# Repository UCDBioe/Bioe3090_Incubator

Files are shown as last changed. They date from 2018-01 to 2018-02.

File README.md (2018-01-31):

Required Libraries
-------------------
* PID_v1
* DallasTemperature
* OneWire

TODO
-----
* students update P,I,D vals in file
* cutoff for 45C heater
* cutoff for low voltage 

Bioe3090_Incubator
------------------

* **class TimeCheck(\_timeTrigger)** - Simple time trigger, needs to be polled to work. When polled with check\_trigger the model will return true if enough time has elapsed to satisfy the condition `(current_time - initial_time) > time_trigger`. If this condition has been met, the poll resets initial_time to current time and returns the boolean true, else false is returned.

* **void check_serial()** - Function that checks the serial port to see if data is available. If data is available, the function reads the data until a newline character is reached. The data is validated to be a correctly formatted JSON string. The JSON string is decoded and the decoded string is stored into global variables for the PID values and heater setpoint.

* **void assign_sensors()** - Startup function to assign the DS18B20 temperature sensors to the outside and inside positions within the incubator.

* **double convert_battery\_voltage(int analog\_reading)** - Converts an analogreading into the voltage of the battery. Uses the global values for the resistors in the voltage divider (resistV1, resistV2)

* **double print_temperature(DeviceAddress deviceAddress, bool jsonFlag)** - Function to print the temperature of a DS18B20 temperature device and to update temperature input for PID control. The temperature of the given device is printed to serial. This is useful for debugging. The temperature value is returned as a double. This can be used to update the temperature input for PID control in the main loop.

* **void json\_output(&double)** - Gathers data, builds JSON message and outputs message to the serial port of theArduino. JSON output string is encoded to contain information for the inside and outside tempertures, the PID output value and the time of the request. This data is then output on the serial port. Takes an address to a double as an input. This double is the input heater value for the PID control. Therefore, the PID heater input value is updated within the json\_output function.

* **void print_address(DeviceAddress deviceAddress)** - Prints the address of the given DS18B20 device.

* **void startup()** - Standard Arduino startup function. Starts serial coms, assigns sensors, set PID mode and sets heater setpoint.

* **void loop()** - Main Arduino program loop.

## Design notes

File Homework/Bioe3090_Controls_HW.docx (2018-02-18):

BIOE3090

Controls and Circuits Homework

30 Pts

Due: 2/13/2018 (Before Class, see canvas)

# Part I: C++ Primer (20 points)

The software provided on the UCDBioe Github account (see below for downloading instructions) contains all of the Arduino firmware required to control the field incubator and provides data communications between the Arduino and an optional terminal running Matlab. However, the firmware is missing failsafe modes for overheating the box and for over discharging the battery. Since it would be difficult to run the native Arduino firmware without the associated hardware, you have been provided an incomplete C++ program that you can use to develop some of the functions that would be useful in implementing these failsafes.

Overview of the bioe3090_HW.cpp code

The code consists of several function definitions and a main function. The main function defines variables and arrays used to make a randomly generated test dataset for battery voltages and temperature readings (battVals and tempVals). The batVals and tempVals array lengths can be changed and the arrays can be modified to have a low and high ranges that allow for the user to build a dataset that has a transition that would cause a failure alarm to be tripped. For example, the program sets up the battery arrays where the first 22 elements have an average value of 12.0V ±0.02V, and the rest of the elements have a value of 11.3V ±0.02V. The alarm should be tripped when the average battery voltage drops below 11.6V. See source code for further details.

The program also sets up two circular buffers to help filter some of the noise out of the data (tempBuffer, battBuffer). These circular buffers are a straightforward way to reduce some of the noise in real-world signals (emulated here as random noise). This is how they work:

For an incoming data stream

datastream = [12.1, 12.2, 12.3, 12.4, 12.7, 12.6, 12.5]

The buffer rolls along the data stream and holds a subset of the overall data

buffer = [12.2, 12.3, 12.4, 12.7]

average(buffer) = 12.4

When new data comes in, we shift the array values to the left and replace the last element with the new data.

buffer = [12.3, 12.4, 12.7, 12.6]

average(buffer) = 12.5

Gaussian distributed random noise is thus reduced by using an averaging filter.

Fixing the Code

The code provided should run, it just will not do what it is supposed to until you fix it. This should allow you to debug the software in a functional state. I would suggest compiling and test running the code early and often rather than trying to complete all of the sections then trying to debug the code. Also, the C-code required to complete this assignment should not be anything terribly advanced. Simple loops, print statements and arithmetic should be sufficient.

1. (5-pts)

Complete the code needed to print the values contained in the arrays in a nicely formatted way. Your output should look similar to Figure 1, where the values are aligned roughly in columns. The code sections are outlined in the bioe3090_HW.cpp file using the tags:

(STUDENT COMPLETE THIS SECTION >> -- HWS1----)

Your code goes here!!!!!!!!!!!!!! Place your code inside the bioe3090_HW.cpp file, but keep it between these tags so I can find it!

(STUDENT COMPLETE THIS SECTION << -- HWS1----)

2. (5-pts.) Complete the code needed to print the average values of a given array. The code sections are outlined in the bioe3090_HW.cpp file using the tags:

(STUDENT COMPLETE THIS SECTION >> -- HWS2----)

Your code goes here!!!!!!!!!!!!!! Place your code inside the bioe3090_HW.cpp file, but keep it between these tags so I can find it!

(STUDENT COMPLETE THIS SECTION << -- HWS2----)

3. (5-pts)

Complete the code needed to shift the buffer array and replace the last value with new data. This is the circular buffer used to average out noise in the signals. The code sections are outlined in the bioe3090_HW.cpp file using the tags:

(STUDENT COMPLETE THIS SECTION >> -- HWS3----)

Your code goes here!!!!!!!!!!!!!! Place your code inside the bioe3090_HW.cpp file, but keep it between these tags so I can find it!

(STUDENT COMPLETE THIS SECTION << -- HWS3----)

4. (5-pts)

Complete the code needed to check if a shutdown condition has been met. The code sections are outlined in the bioe3090_HW.cpp file using the tags:

(STUDENT COMPLETE THIS SECTION >> -- HWS4----)

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

(STUDENT COMPLETE THIS SECTION << -- HWS4----)

You may get a warning when you compile the code before you have fixed all of the sections: warning: control reaches end of non-void function [-Wreturn-type]. This warning simply means that you have a function defined to return some value and no value was returned. It will fix itself when you have valid return statements.

What to turn in for part 1

Your output should look similar to Figure 1. Turn in your .cpp file, put your name in the filename, i.e. steve_lammers_bioe3090_HW.cpp

Your code should compile and run. You will be mostly graded based on whether your code produces the correct output when it is compiled and run. You should not need to include any other libraries to do this assignment.

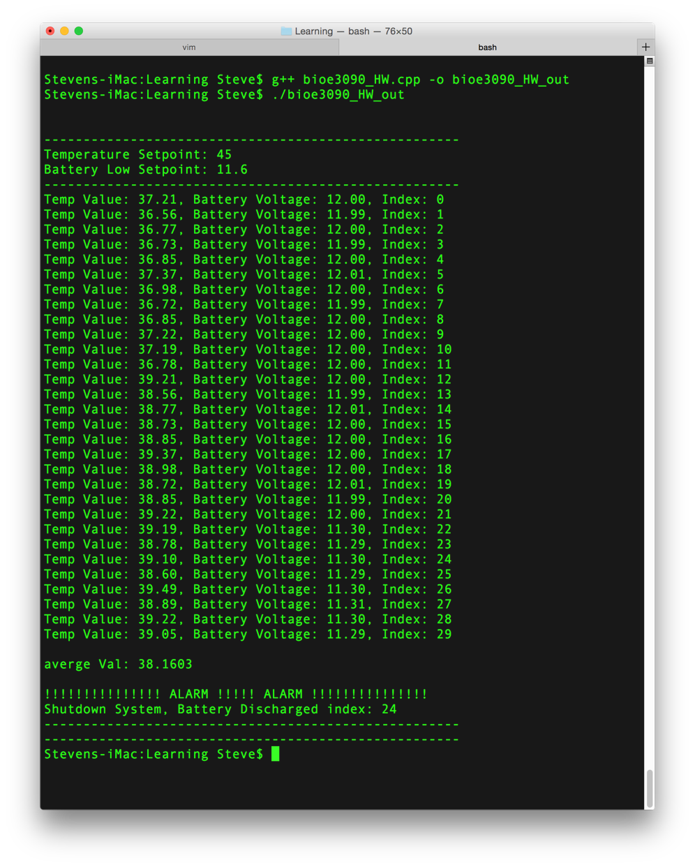
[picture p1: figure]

Figure 1: Output from completed C++ program.

Downloading Instructions:

The github repository is now public, so you can download the files needed to do this homework and to build your first design project.

https://github.com/UCDBioe/Bioe3090_Incubator

Remember to click the green "Clone or Download" button to be able to download the files. The homework is in the homework directory.

# Part 2: Soldering and Components (10 points)

Watch the “Soldering Video” and the “Multimeter Tutorial Video” posted to Canvas-Modules-Technical Content and Lab Module. Answer the following questions.

1. Why do you need to keep your solder tip clean?
2. Why do we tin the soldering iron?
3. What shape indicates a good solder joint on a printer circuit board?
4. What is continuity?
5. Can you use a multimeter to measure a resistor that is wired into a circuit?
6. (5-pts) What happens if you do not remember to splice in the multimeter when checking a circuit and instead use the probes as you would use to check a voltage reading? For example, you went to check the amps of a 120V wall outlet and plugged in the probes directly to the outlet as was demonstrated in the video when AC voltage was being measured? Describe how this could be dangerous and potentially damage equipment.

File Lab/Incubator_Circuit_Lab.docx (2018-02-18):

BioE 3090 Junior Design

Incubator Circuit Lab

2/8/2018

# Objective

The objective of this lab is to build and test the circuit you will be using to heat the incubator prototype and to begin tuning the PID controller to control the incubator temperature. This will probably take 2 class periods.

# Parts

Part | Quantity
DS18B20 Temperature Sensor | 2
Heater Kapton Tape | 1
MOSFET 20N06L | 1
Heat Sink for TO220 | 1
Arduino Uno | 1
USB | 1
LED | 1
Resistor 4.7, 3.3M, 2.2.M, 10k, 390 | 1 ea
Doide Schottkey | 1
Fuse Holder | 1
Breadboard | 1
Heat Sink TO220 | 1
Glass Fuse 2A | 1
Switch | 1
Power Jack | 1

# What to Turn In / Lab Output

1. A screenshot of the Matlab UI running. (5-pts)
2. Adjust P, I, D values in real time to better tune the system. (5-pts)
  a. Describe how the system is behaving. Are you able to get it tuned so that the temperature measured tracks exactly with the setpoint temperature.
3. An Excel plot of Inside Temp and Outside temperature vs Time on the Left Axis, Plot of Battery Voltage in time on the Right Axis. (10 pts)
  a. You can get this data from your saved text file.

# Electronics Diagram

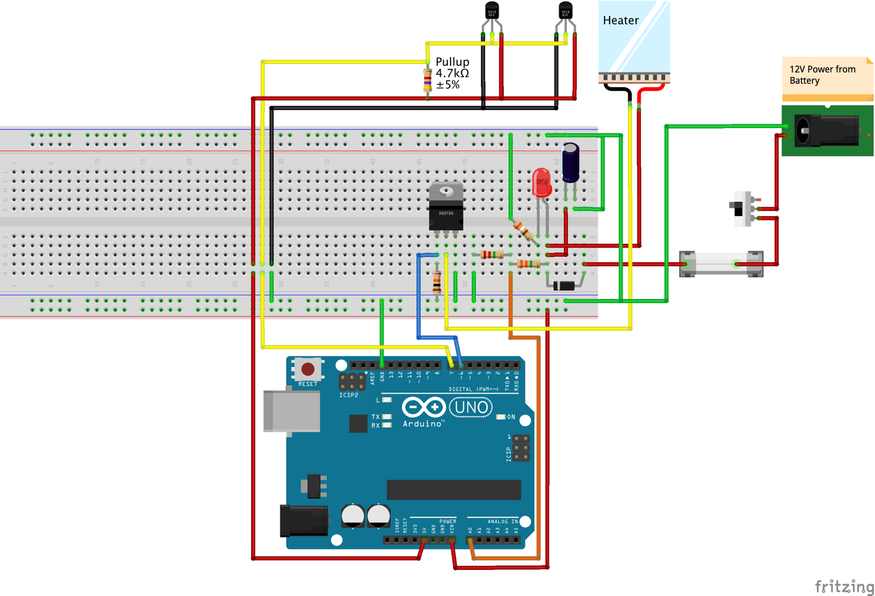
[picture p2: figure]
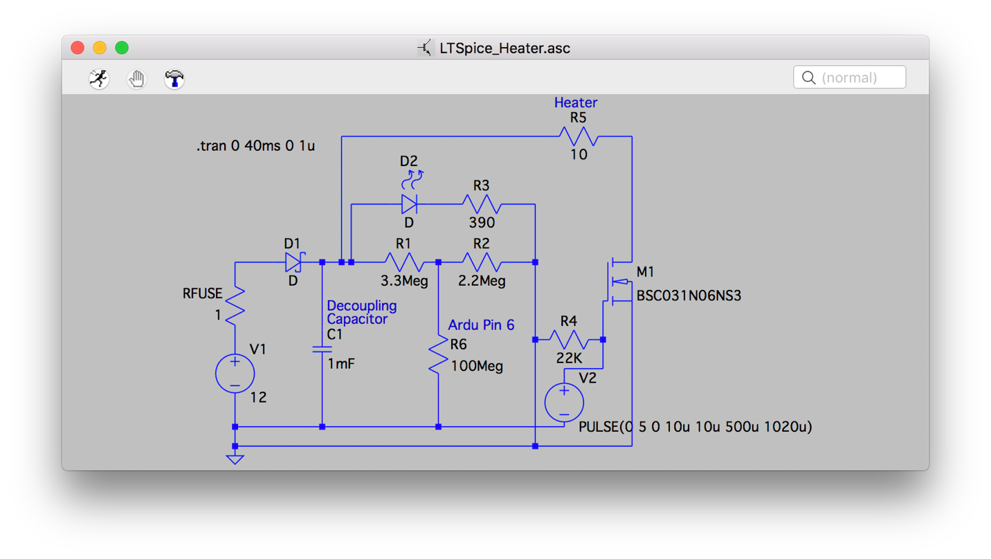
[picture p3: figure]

# Work Plan

1. Station Rotation – Soldering
  a. One group at a time, soldering training.
2. Build Power Supply Circuit
  a. Use 22Ga solid core hookup wire for breadboard connections.
  b. Wire power supply circuit to breadboard. Test voltage and grounds.
    i. Power jack, fuse, protection diode, decoupling capacitor and ground buses.
  c. Test Power Supply circuit before building the rest of the circuit
    i. You can layout the rest of the circuit components just ensure they cannot get powered before testing the power circuitry.
    ii. Are your breadboard ground and power rails reading +12V as expected?
  d. Unplug power supply circuit and measure voltage
    i. There may be remaining power on the breadboard, some power supplies have internal capacitors that will remain charged for a short time after unplugging the circuit.
3. Layout the remaining components
4. Attach temperature sensors and heater to incubator.
  a. Heaters are power elements, so you’ll need to us wire that has sufficient cross sectional area to carry the necessary current.
  b. The heaters are not attached to the breadboard, so it makes better sense to use stranded wire, instead of solid core hookup wire.
  c. 22Ga Stranded wire should work well for the heater, but you will need to solder / heat shrink a small section of hookup wire to be able to push it into the breadboard.
  d. DS18B20 temperature sensors are digital electronics and do not require high currents. 22Ga wire would be overkill, cost more, and would be less flexible.
    i. Use 28Ga wire for these low-power electronics.
  e. It is Styrofoam, so should be pretty easy to make penetrations.
  f. The supplied heater is fairly low power, so avoid unnecessary holes.
    i. Probably not a great idea to just run the wires under the lid.
5. Flash the firmware onto the Arduino
  a. Firmware is located in Bioe3090_Incubator -> Bioe3090_Incubator.ino
6. Load and run the Matlab UI
  a. Bioe3090_Incubator -> Matlab -> PID_Datalogger -> Plot_Serial.m
  b. A dialog box will pop up to select the Arduino connection port. This will have the same name as the Port on the Arduino IDE -> Tools -> Port menu.
  c. When you run the software the UI should automatically begin collecting data after 1-2 seconds and the plots will begin updating.
  d. If you change the P, I, D, or Temperature Setpoint then these values will be updated in the Arduino in real time.
7. To write data to file
  a. The “Write to File” button opens a dialog box to save a text file.
  b. The text file will write any data stored in cache within the Matlab program and will then proceed to log every datum as it is received by the UI.

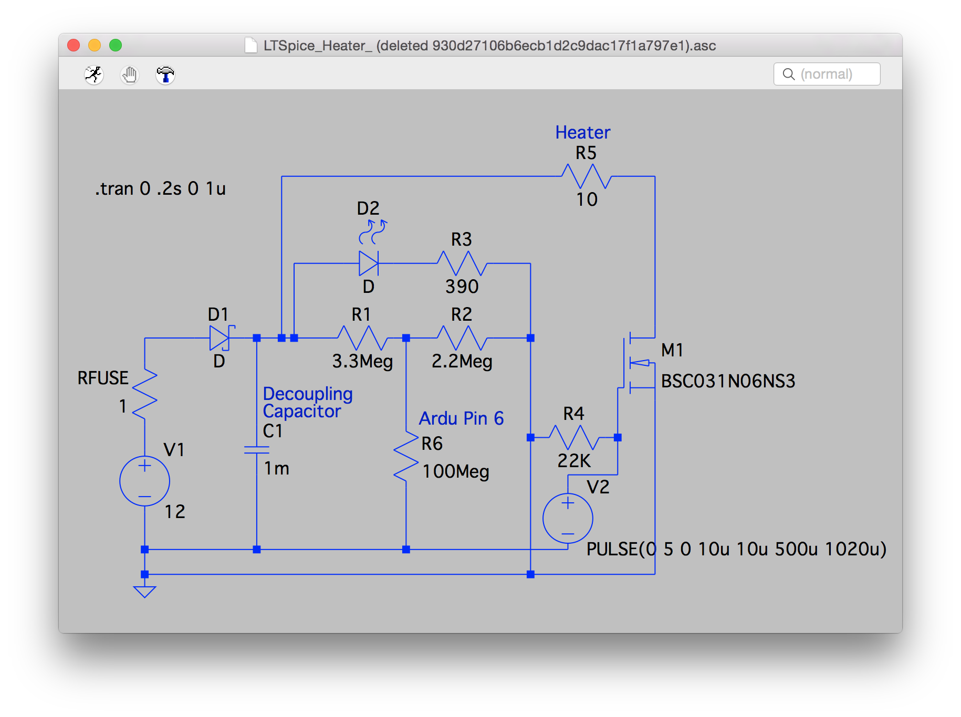
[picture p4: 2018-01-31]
Diagrams/LTSpice_schematics/Images/Heater_sch1.png

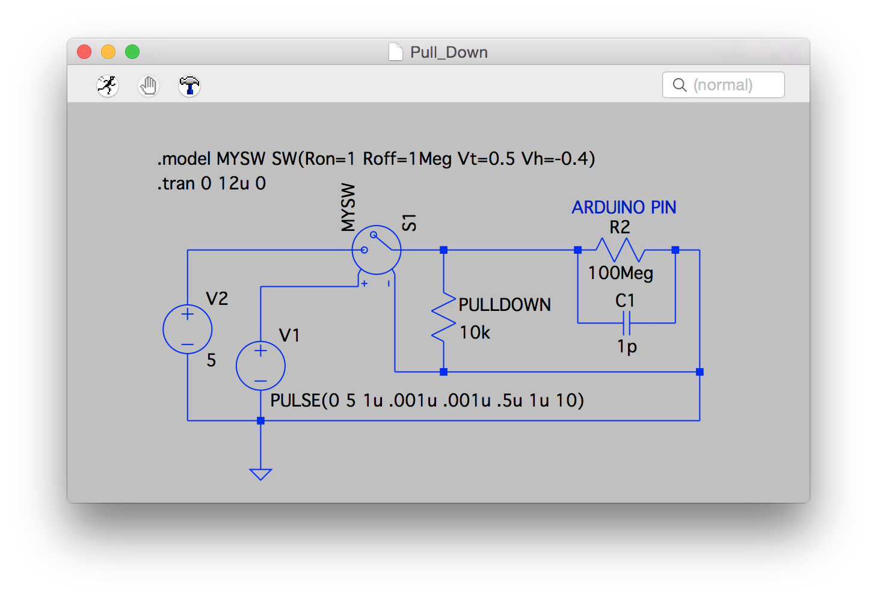
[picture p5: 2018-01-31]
Diagrams/LTSpice_schematics/Images/PullDown_sch1.png

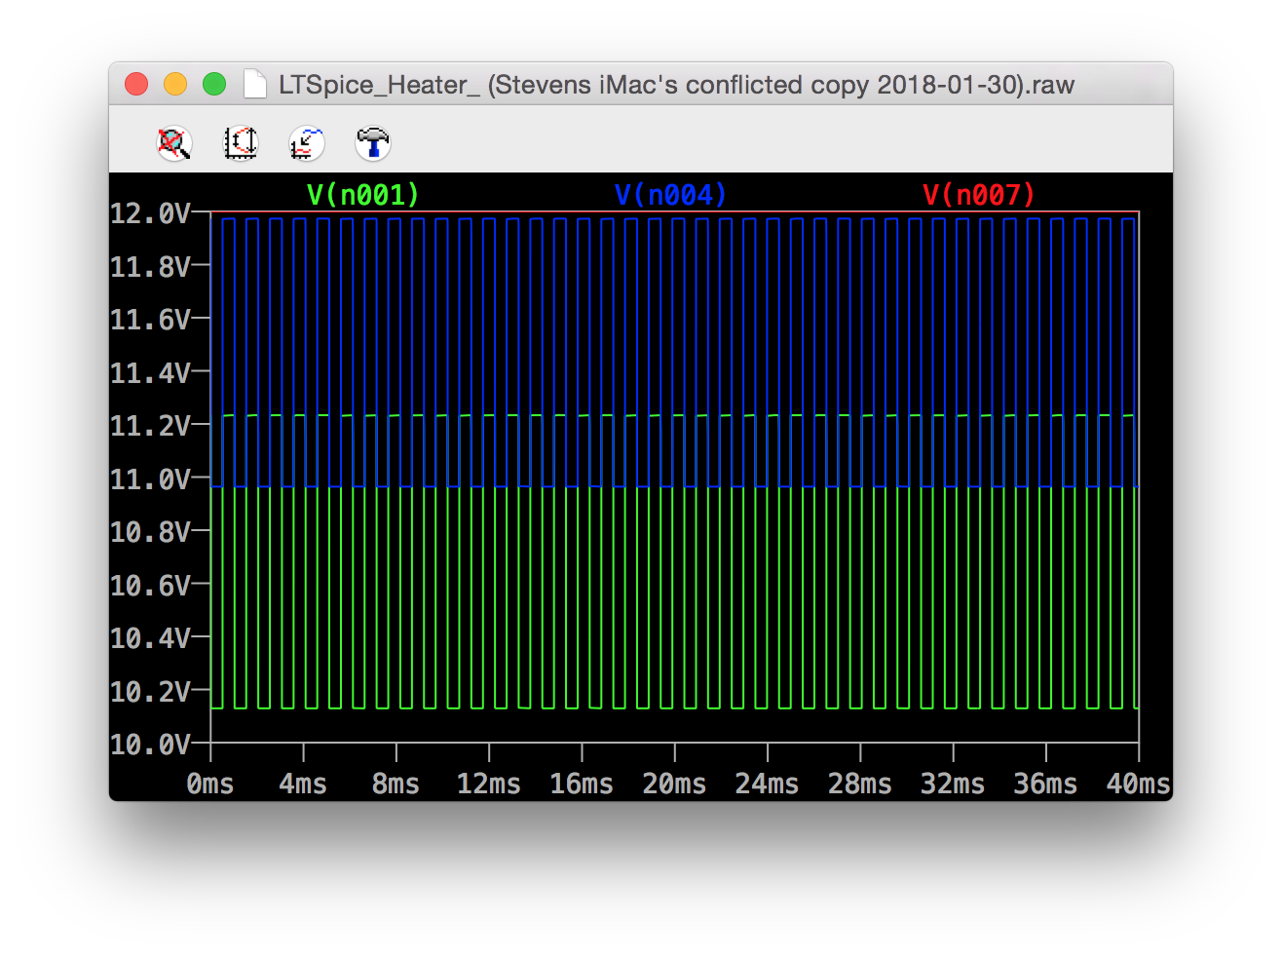
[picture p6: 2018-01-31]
Diagrams/LTSpice_schematics/Images/Heater_Supply_NoCap.png

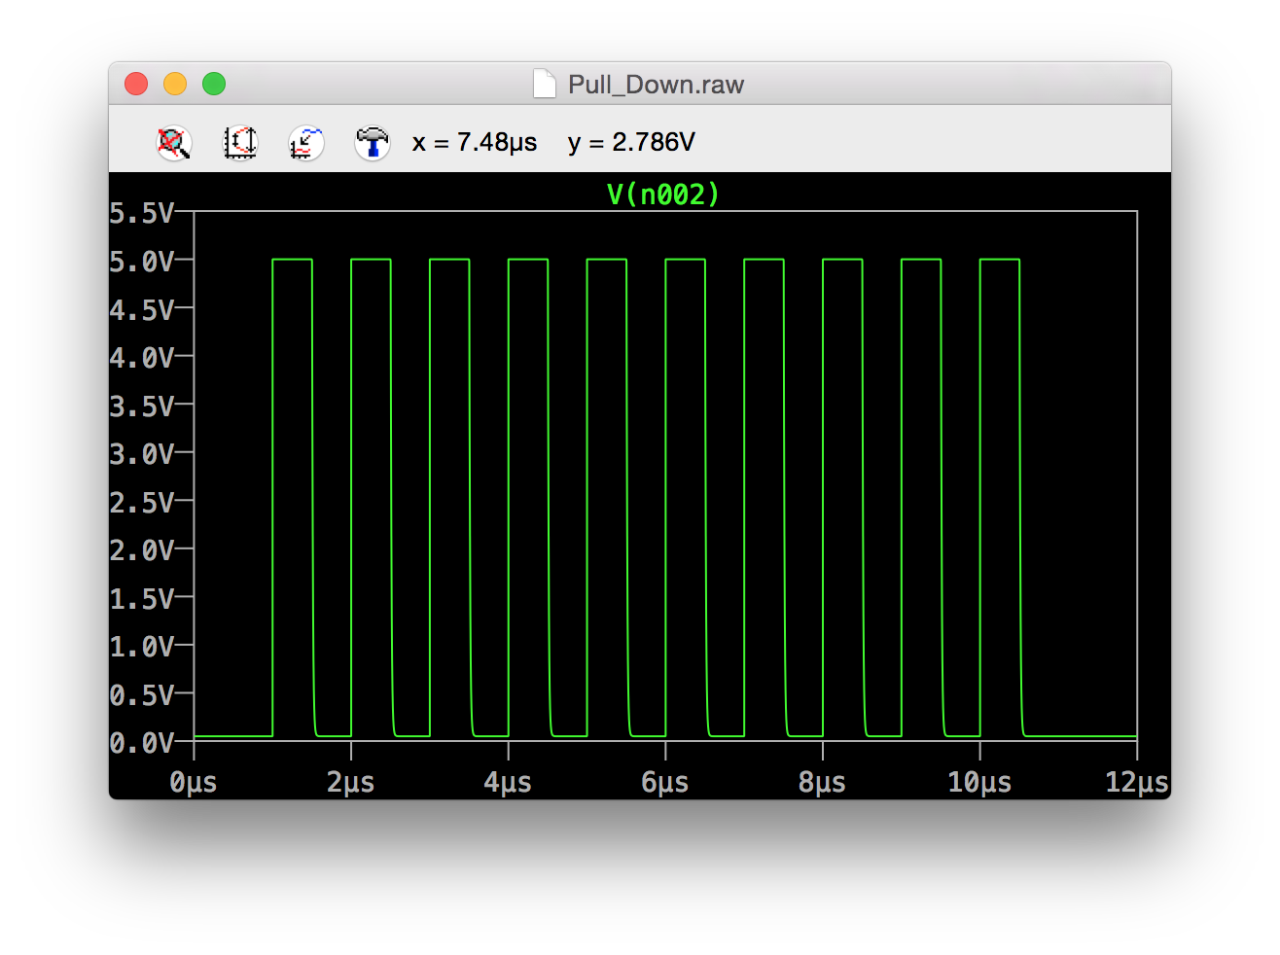
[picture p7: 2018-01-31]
Diagrams/LTSpice_schematics/Images/PullDown_res1.png

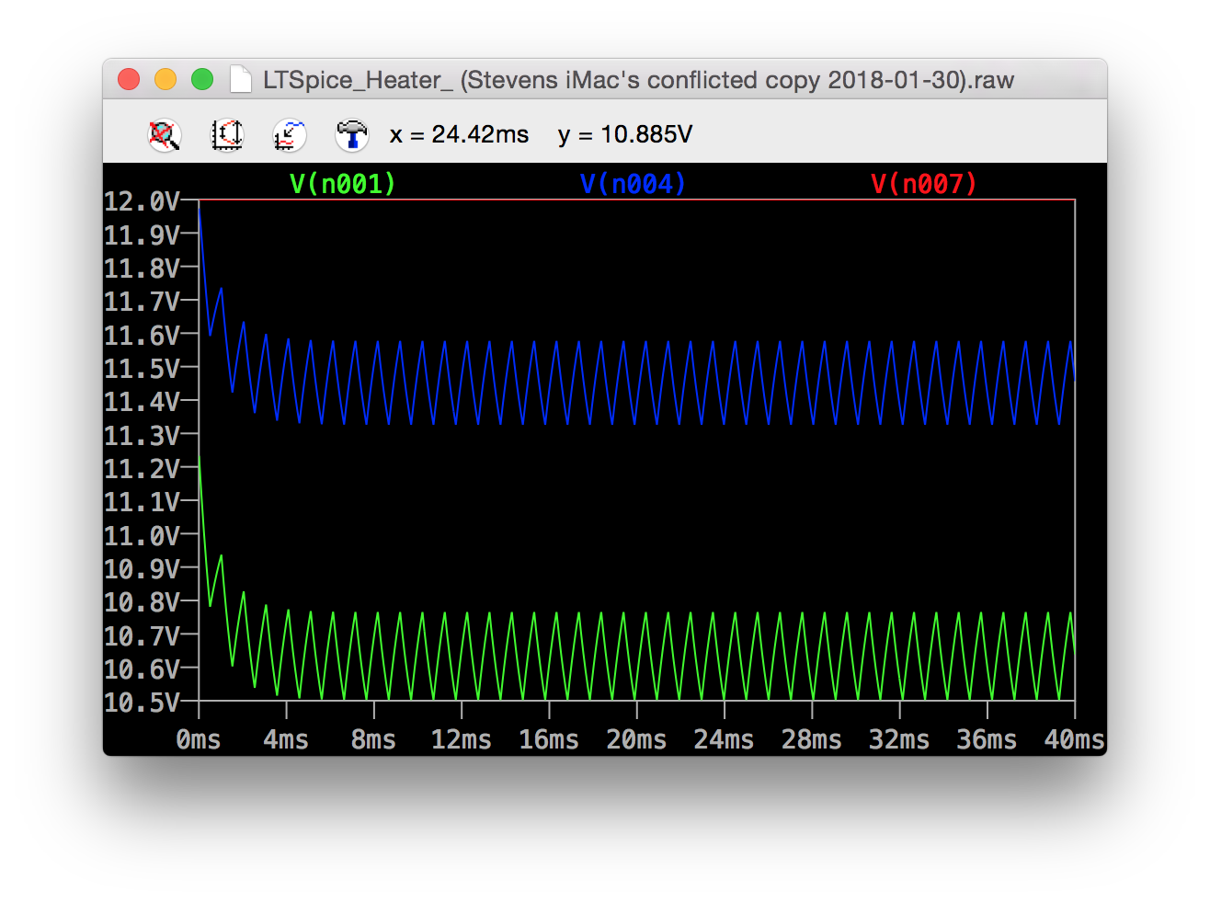
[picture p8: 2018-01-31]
Diagrams/LTSpice_schematics/Images/Heater_Supply_Cap.png

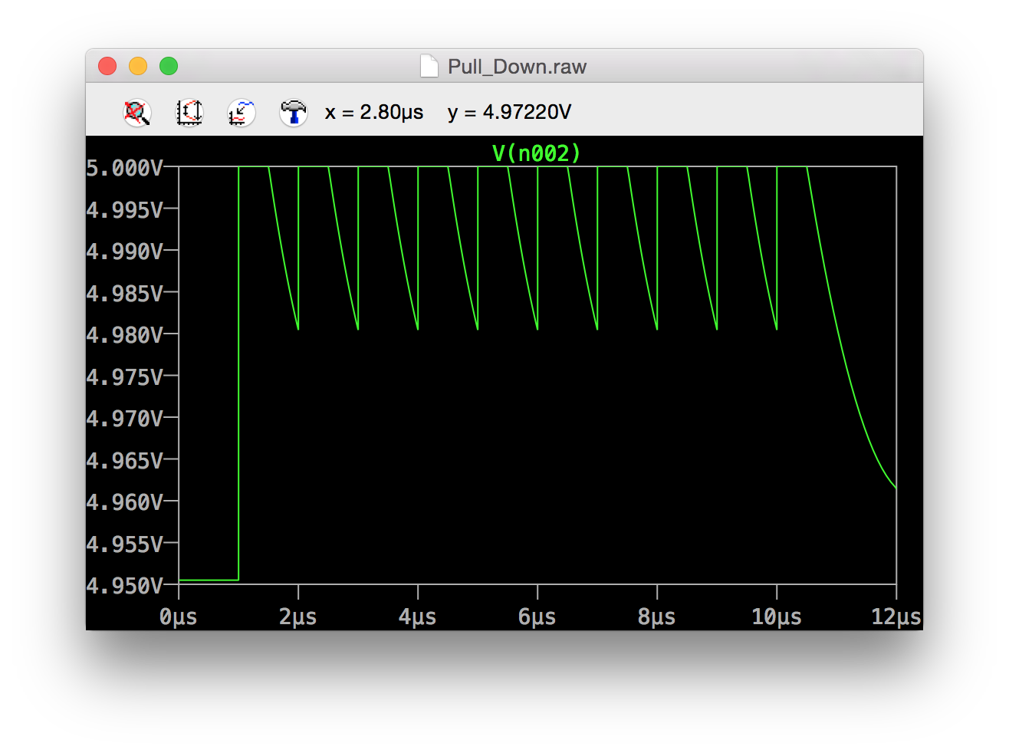
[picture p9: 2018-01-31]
Diagrams/LTSpice_schematics/Images/PullDown_res2.png

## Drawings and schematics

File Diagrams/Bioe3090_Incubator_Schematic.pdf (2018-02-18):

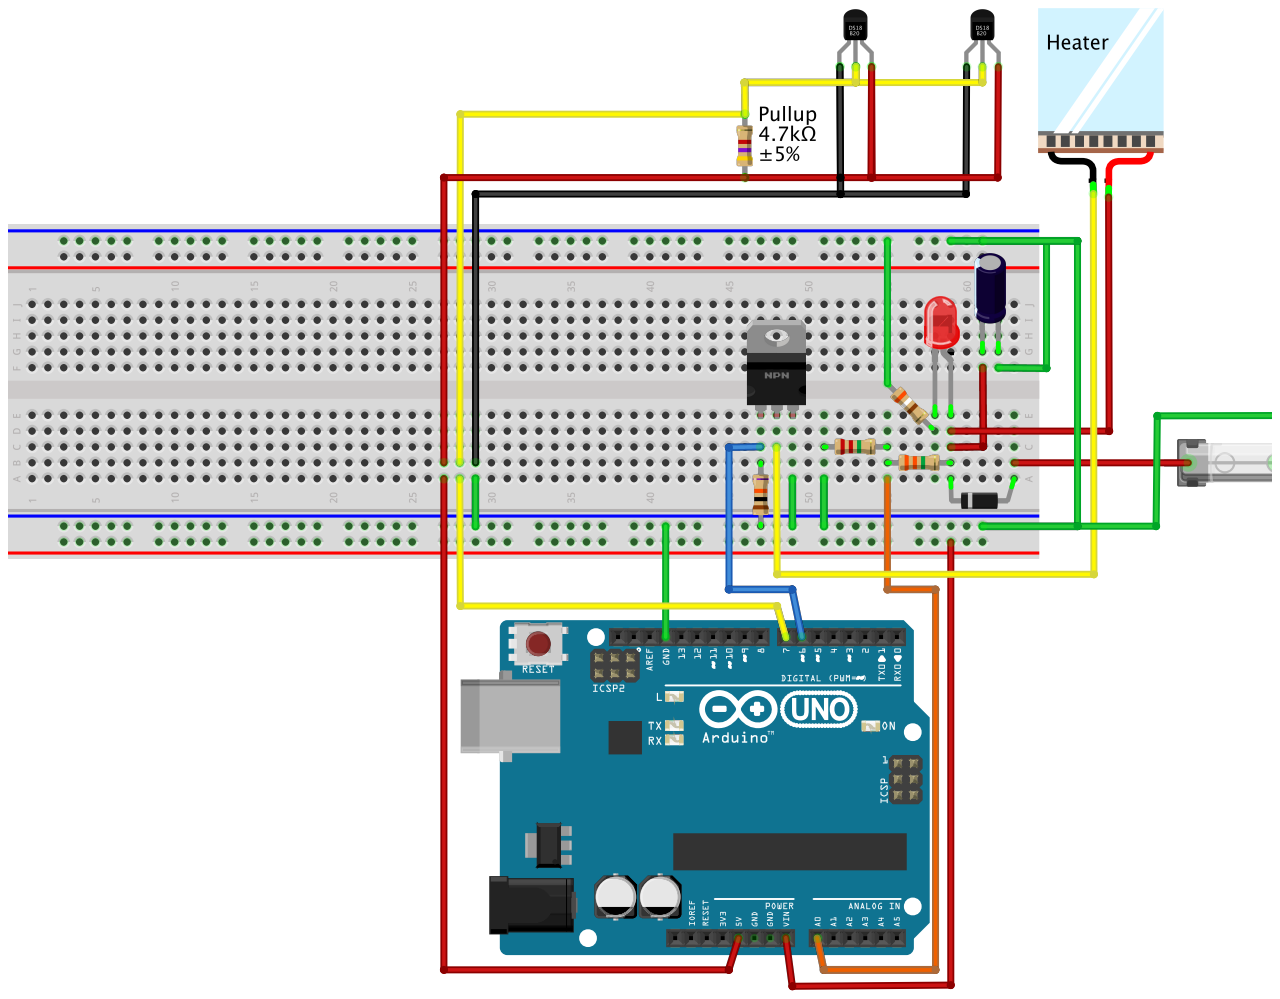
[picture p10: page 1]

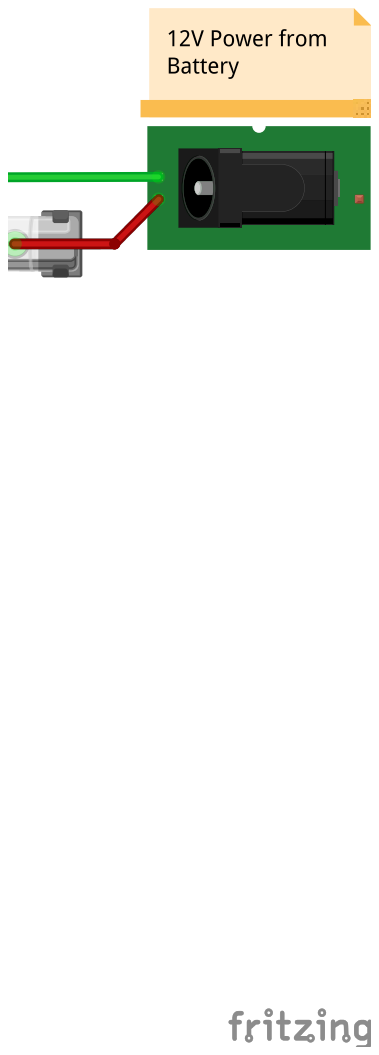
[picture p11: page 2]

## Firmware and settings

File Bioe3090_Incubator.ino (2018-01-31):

/* Bioe3090_Incubator.ino - Example controls for Bioe 3090 Incubator Project
	Created by: Steve Lammers, 12/11/2017
	Released to the public domain.
*/

// PID library for controls
#include <PID_v1.h>
// DS18B20 temperature sensor libraries
#include <OneWire.h>
#include <DallasTemperature.h>
// JSON Library
#include <ArduinoJson.h>

// Pin Values
// Data wire is plugged into port 2 on the Arduino
#define ONE_WIRE_BUS 7
// Set heater pin to analog pin 3
#define HEATER_PIN 6
// Refresh rate for checking temperatures and updating PID input milliseconds, default 1000
#define TEMP_CHK_MS 100

#define BATTERY_PIN 0 
// Define global variables
double batteryVoltage;
double resistV1 = 3300.0;
double resistV2 = 2200.0; 
// heaterSetpoint is set in check_serial function
// heaterInput is set by print_temperature return in main loop
// heaterOutput is used in main loop to effect heater contol
double heaterSetpoint, heaterInput, heaterOutput;

String inString = "";
// Create a heaterPID object of type PID - class loaded by thge PID_v1 library
//
double pVal = 20, iVal = 5, dVal = 1;
// variables passed by reference as outlined in the class.
PID heaterPID(&heaterInput, &heaterOutput, &heaterSetpoint,pVal, iVal, dVal, DIRECT);

// Setup a oneWire instance to communicate with any OneWire device (not just Maxim/Dallas temperature ICs)
OneWire oneWire(ONE_WIRE_BUS);

// Pass our oneWire reference to Dallas Temperature. 
DallasTemperature sensors(&oneWire);

// arrays to hold device address
DeviceAddress insideThermometer, outsideThermometer;

// Create JSON object.
//StaticJsonBuffer<200> jsonBuffer;
//JsonObject& jsonRoot = jsonBuffer.createObject();
bool jsonFlag = true; 

class TimeCheck{
	unsigned long timeNow, timePrevious, timeTrigger;

	public:
	TimeCheck(unsigned long _timeTrigger){
		timePrevious = millis();
		timeNow = millis();
		timeTrigger = _timeTrigger;
	}
	
	void set_trigger(unsigned long _timeTrigger){
		timeTrigger = _timeTrigger;
	} 

	bool check_trigger(){
		bool triggered = false;
		timeNow = millis();
		unsigned long deltaTime = timeNow - timePrevious;
		if (deltaTime > timeTrigger ){
			timePrevious = timeNow;
			triggered = true;
		}
		else{ triggered = false; }
		
		return triggered;
	}
}; // class TimeCheck

// Create a clock to print the current temperature every second
TimeCheck printTempClock(TEMP_CHK_MS);




void check_serial(){
  // Ask user to input the setpoint for the heater.
  //Serial.print("Enter temperature setpoint in degrees Celsius: ");
  // send data only when you receive data:
  // Clear the input string 
  while (Serial.available() > 0) {
    // read the incoming byte:
    int incomingByte = Serial.read();
    /*
    // if the data is a digit, add it to inString
    if (isDigit(incomingByte)){
      inString += (char)incomingByte;
    }
    else{
      // ignore if the incomming byte is a carrige return or newline char
      if (incomingByte == '\n' || incomingByte == '\r'){
          Serial.println("newline or CR");
        }
      else{
        Serial.println("Incompatible character, use only numbers");
      }
    }
    */

    inString += (char)incomingByte;
    // Check if the incoming byte is a newline character
    if (incomingByte == '\n'){
      // say what you got:
      Serial.print("I received: ");
      // Set temperature setpoint to the inString number
      //heaterSetpoint = inString.toFloat();
      //Serial.println(heaterSetpoint);

      // json format: {"pVal":2,"iVal":5,"dVal":1,"tSP":20}
      Serial.println(inString);
      // Create JSON object, must create json object as a local objet here, not
      //  as a global as typical in the example docs in the ArduinoJson library.
      //  Otherwise the object is not destroyed after the loop is complete and
      //  if the parsing does not succeed then future calls to parse incomming
      //  correctly formatted json strings will also fail. Making the object local
      //  fixes this problem.
      StaticJsonBuffer<200> jsonBuffer;
      //JsonObject& jsonRoot = jsonBuffer.createObject();
      JsonObject& jsonRoot = jsonBuffer.parseObject(inString);

      // Test if parsing succeeds.
      if (!jsonRoot.success()) {
        Serial.println("parseObject() failed");
        // Clear the input string 
        inString = "";
        return;
      }

      //double tSP = jsonRoot["tSP"];
      //heaterSetpoint = tSP;
      heaterSetpoint = jsonRoot["tSP"];
      Serial.println(heaterSetpoint);

      pVal = jsonRoot["pVal"];
      iVal = jsonRoot["iVal"];
      dVal = jsonRoot["dVal"];
      heaterPID.SetTunings(pVal, iVal, dVal);
      
      // Clear the input string 
      inString = "";
    }

  } 
} // << check_serial


void	assign_sensors(){
  // Assign address manually. The addresses below will beed to be changed
  // to valid device addresses on your bus. Device address can be retrieved
  // by using either oneWire.search(deviceAddress) or individually via
  // sensors.getAddress(deviceAddress, index)
  // Note that you will need to use your specific address here
  //insideThermometer = { 0x28, 0x1D, 0x39, 0x31, 0x2, 0x0, 0x0, 0xF0 };

  // Method 1:
  // Search for devices on the bus and assign based on an index. Ideally,
  // you would do this to initially discover addresses on the bus and then 
  // use those addresses and manually assign them (see above) once you know 
  // the devices on your bus (and assuming they don't change).
  if (!sensors.getAddress(outsideThermometer, 0)) Serial.println("Unable to find address for Device 0");
  if (!sensors.getAddress(insideThermometer, 1)) Serial.println("Unable to find address for Device 1"); 

  // method 2: search()
  // search() looks for the next device. Returns 1 if a new address has been
  // returned. A zero might mean that the bus is shorted, there are no devices, 
  // or you have already retrieved all of them. It might be a good idea to 
  // check the CRC to make sure you didn't get garbage. The order is 
  // deterministic. You will always get the same devices in the same order
  //
  // Must be called before search()
  //oneWire.reset_search();
  // assigns the first address found to insideThermometer
  //if (!oneWire.search(insideThermometer)) Serial.println("Unable to find address for insideThermometer");

  // show the addresses we found on the bus
  Serial.print("Device 0 Address: ");
  print_address(insideThermometer);
  Serial.println();

  Serial.print("Device 1 Address: ");
  print_address(outsideThermometer);
  Serial.println();

  // set the resolution to 9 bit (Each Dallas/Maxim device is capable of several different resolutions)
  sensors.setResolution(insideThermometer, 9);
  sensors.setResolution(outsideThermometer, 9);
 
  Serial.print("Device 0 Resolution: ");
  Serial.print(sensors.getResolution(insideThermometer), DEC); 
  Serial.println();
  Serial.print("Device 1 Resolution: ");
  Serial.print(sensors.getResolution(outsideThermometer), DEC); 
  Serial.println();
} // << assign_sensors

double convert_battery_voltage(int analog_reading){
  // Converts the analog reading to battery voltge
  double volts = (double)analog_reading/1023.0*5.0*(resistV1 + resistV2)/resistV2;

  return volts;
}

// function to print the temperature for a device
double print_temperature(DeviceAddress deviceAddress)
{
  // request to all devices on the bus
  Serial.print("Requesting temperatures...");
  sensors.requestTemperatures(); // Send the command to get temperatures
  Serial.println("DONE");

  // method 1 - slower
  //Serial.print("Temp C: ");
  //Serial.print(sensors.getTempC(deviceAddress));
  //Serial.print(" Temp F: ");
  //Serial.print(sensors.getTempF(deviceAddress)); // Makes a second call to getTempC and then converts to Fahrenheit

  // method 2 - faster
  double tempC = sensors.getTempC(deviceAddress);
  Serial.print("Temp C: ");
  Serial.print(tempC);
  Serial.print(" Temp F: ");
  Serial.println(DallasTemperature::toFahrenheit(tempC)); // Converts tempC to Fahrenheit
  
  return tempC;
}

// Gathers output data, format as JSON and output as serial communication
double json_output(double *pidInputControl)
{ 
  
  // request to all devices on the bus
  //Serial.print("Requesting temperatures...");
  sensors.requestTemperatures(); // Send the command to get temperatures
  //Serial.println("DONE");
  //delay(200);

  double tempCinside = sensors.getTempC(insideThermometer);
  double tempCoutside = sensors.getTempC(outsideThermometer);
  // *pidInputControl: used to update PID input value through pointer
  *pidInputControl = tempCinside; 
  
  // Measure battery voltage
  int analog_batt = analogRead(BATTERY_PIN);
  batteryVoltage = convert_battery_voltage(analog_batt);

  // Create JSON object.
  StaticJsonBuffer<200> jsonBuffer;
  JsonObject& jsonRoot = jsonBuffer.createObject();
  jsonRoot["temperatureInside"] = tempCinside;
  jsonRoot["temperatureOutside"] = tempCoutside;
  jsonRoot["temperatureSetpoint"] = heaterSetpoint;
  jsonRoot["PIDoutput"] = heaterOutput;
  jsonRoot["time"] = millis();//(millis() * 205 ) >> 11; //millis()/1000;
  jsonRoot["batteryVolts"] = batteryVoltage;
  jsonRoot.printTo(Serial);
  //Serial.print("Current temp string: ");
  //Serial.println(String(tempC));
  Serial.println();
}

// function to print a device address
void print_address(DeviceAddress deviceAddress)
{
  for (uint8_t i = 0; i < 8; i++)
  {
    if (deviceAddress[i] < 16) Serial.print("0");
    Serial.print(deviceAddress[i], HEX);
  }
}


void setup(){
  // Start serial comms
	Serial.begin(9600);

	while (!Serial) {
		; // Wait for serial to connect
	}
	
  // locate devices on the bus
  Serial.print("Locating devices...");
  sensors.begin();
  Serial.print("Found ");
  Serial.print(sensors.getDeviceCount(), DEC);
  Serial.println(" devices.");
  assign_sensors();	


	Serial.println("\n\n Incubator Control");
	Serial.println("Type in heater setpoint in degrees Celsius, numbers only");

  //turn the PID on
	heaterPID.SetMode(AUTOMATIC);

  // Set an initial heater Setpoint for DEBUG
  heaterSetpoint = 25;
}


void loop(){
  // Check the serial comms to see if the heater setpoint changed
  check_serial();
	if (printTempClock.check_trigger()){
		// Get new temperature reading, compute PID and control heater 
		//heaterInput = print_temperature(insideThermometer); 
    //heaterPID.Compute(); 
    // move compute out of the check_trigger
    //analogWrite(HEATER_PIN, heaterOutput);
    
    // Output data to serial.
    json_output(&heaterInput);
    heaterPID.Compute(); 
    // move compute out of the check_trigger
    analogWrite(HEATER_PIN, heaterOutput);

	}
 
  //DEL delay(1000);
}

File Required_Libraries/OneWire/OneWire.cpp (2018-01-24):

/*
Copyright (c) 2007, Jim Studt  (original old version - many contributors since)

The latest version of this library may be found at:
  http://www.pjrc.com/teensy/td_libs_OneWire.html

OneWire has been maintained by Paul Stoffregen (paul@pjrc.com) since
January 2010.  At the time, it was in need of many bug fixes, but had
been abandoned the original author (Jim Studt).  None of the known
contributors were interested in maintaining OneWire.  Paul typically
works on OneWire every 6 to 12 months.  Patches usually wait that
long.  If anyone is interested in more actively maintaining OneWire,
please contact Paul.

Version 2.3:
  Unknonw chip fallback mode, Roger Clark
  Teensy-LC compatibility, Paul Stoffregen
  Search bug fix, Love Nystrom

Version 2.2:
  Teensy 3.0 compatibility, Paul Stoffregen, paul@pjrc.com
  Arduino Due compatibility, http://arduino.cc/forum/index.php?topic=141030
  Fix DS18B20 example negative temperature
  Fix DS18B20 example's low res modes, Ken Butcher
  Improve reset timing, Mark Tillotson
  Add const qualifiers, Bertrik Sikken
  Add initial value input to crc16, Bertrik Sikken
  Add target_search() function, Scott Roberts

Version 2.1:
  Arduino 1.0 compatibility, Paul Stoffregen
  Improve temperature example, Paul Stoffregen
  DS250x_PROM example, Guillermo Lovato
  PIC32 (chipKit) compatibility, Jason Dangel, dangel.jason AT gmail.com
  Improvements from Glenn Trewitt:
  - crc16() now works
  - check_crc16() does all of calculation/checking work.
  - Added read_bytes() and write_bytes(), to reduce tedious loops.
  - Added ds2408 example.
  Delete very old, out-of-date readme file (info is here)

Version 2.0: Modifications by Paul Stoffregen, January 2010:
http://www.pjrc.com/teensy/td_libs_OneWire.html
  Search fix from Robin James
    http://www.arduino.cc/cgi-bin/yabb2/YaBB.pl?num=1238032295/27#27
  Use direct optimized I/O in all cases
  Disable interrupts during timing critical sections
    (this solves many random communication errors)
  Disable interrupts during read-modify-write I/O
  Reduce RAM consumption by eliminating unnecessary
    variables and trimming many to 8 bits
  Optimize both crc8 - table version moved to flash

Modified to work with larger numbers of devices - avoids loop.
Tested in Arduino 11 alpha with 12 sensors.
26 Sept 2008 -- Robin James
http://www.arduino.cc/cgi-bin/yabb2/YaBB.pl?num=1238032295/27#27

Updated to work with arduino-0008 and to include skip() as of
2007/07/06. --RJL20

Modified to calculate the 8-bit CRC directly, avoiding the need for
the 256-byte lookup table to be loaded in RAM.  Tested in arduino-0010
-- Tom Pollard, Jan 23, 2008

Jim Studt's original library was modified by Josh Larios.

Tom Pollard, pollard@alum.mit.edu, contributed around May 20, 2008

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
Much of the code was inspired by Derek Yerger's code, though I don't
think much of that remains.  In any event that was..
    (copyleft) 2006 by Derek Yerger - Free to distribute freely.

The CRC code was excerpted and inspired by the Dallas Semiconductor
sample code bearing this copyright.
//---------------------------------------------------------------------------
// Copyright (C) 2000 Dallas Semiconductor Corporation, All Rights Reserved.
//
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
  FITNESS FOR A PARTICULAR PURPOSE AND NONINFRINGEMENT.
// IN NO EVENT SHALL DALLAS SEMICONDUCTOR BE LIABLE FOR ANY CLAIM, DAMAGES
// OR OTHER LIABILITY, WHETHER IN AN ACTION OF CONTRACT, TORT OR OTHERWISE,
// ARISING FROM, OUT OF OR IN CONNECTION WITH THE SOFTWARE OR THE USE OR
// OTHER DEALINGS IN THE SOFTWARE.
//
// Except as contained in this notice, the name of Dallas Semiconductor
// shall not be used except as stated in the Dallas Semiconductor
// Branding Policy.
//--------------------------------------------------------------------------
*/

#include "OneWire.h"


OneWire::OneWire(uint8_t pin)
{
	pinMode(pin, INPUT);
	bitmask = PIN_TO_BITMASK(pin);
	baseReg = PIN_TO_BASEREG(pin);
#if ONEWIRE_SEARCH
	reset_search();
#endif
}


// Perform the onewire reset function.  We will wait up to 250uS for
// the bus to come high, if it doesn't then it is broken or shorted
// and we return a 0;
//
// Returns 1 if a device asserted a presence pulse, 0 otherwise.
//
uint8_t OneWire::reset(void)
{
	IO_REG_TYPE mask = bitmask;
	volatile IO_REG_TYPE *reg IO_REG_ASM = baseReg;
	uint8_t r;
	uint8_t retries = 125;

	noInterrupts();
	DIRECT_MODE_INPUT(reg, mask);
	interrupts();
	// wait until the wire is high... just in case
	do {
		if (--retries == 0) return 0;
		delayMicroseconds(2);
	} while ( !DIRECT_READ(reg, mask));

	noInterrupts();
	DIRECT_WRITE_LOW(reg, mask);
	DIRECT_MODE_OUTPUT(reg, mask);	// drive output low
	interrupts();
	delayMicroseconds(480);
	noInterrupts();
	DIRECT_MODE_INPUT(reg, mask);	// allow it to float
	delayMicroseconds(70);
	r = !DIRECT_READ(reg, mask);
	interrupts();
	delayMicroseconds(410);
	return r;
}

//
// Write a bit. Port and bit is used to cut lookup time and provide
// more certain timing.
//
void OneWire::write_bit(uint8_t v)
{
	IO_REG_TYPE mask=bitmask;
	volatile IO_REG_TYPE *reg IO_REG_ASM = baseReg;

	if (v & 1) {
		noInterrupts();
		DIRECT_WRITE_LOW(reg, mask);
		DIRECT_MODE_OUTPUT(reg, mask);	// drive output low
		delayMicroseconds(10);
		DIRECT_WRITE_HIGH(reg, mask);	// drive output high
		interrupts();
		delayMicroseconds(55);
	} else {
		noInterrupts();
		DIRECT_WRITE_LOW(reg, mask);
		DIRECT_MODE_OUTPUT(reg, mask);	// drive output low
		delayMicroseconds(65);
		DIRECT_WRITE_HIGH(reg, mask);	// drive output high
		interrupts();
		delayMicroseconds(5);
	}
}

//
// Read a bit. Port and bit is used to cut lookup time and provide
// more certain timing.
//
uint8_t OneWire::read_bit(void)
{
	IO_REG_TYPE mask=bitmask;
	volatile IO_REG_TYPE *reg IO_REG_ASM = baseReg;
	uint8_t r;

	noInterrupts();
	DIRECT_MODE_OUTPUT(reg, mask);
	DIRECT_WRITE_LOW(reg, mask);
	delayMicroseconds(3);
	DIRECT_MODE_INPUT(reg, mask);	// let pin float, pull up will raise
	delayMicroseconds(10);
	r = DIRECT_READ(reg, mask);
	interrupts();
	delayMicroseconds(53);
	return r;
}

//
// Write a byte. The writing code uses the active drivers to raise the
// pin high, if you need power after the write (e.g. DS18S20 in
// parasite power mode) then set 'power' to 1, otherwise the pin will
// go tri-state at the end of the write to avoid heating in a short or
// other mishap.
//
void OneWire::write(uint8_t v, uint8_t power /* = 0 */) {
    uint8_t bitMask;

    for (bitMask = 0x01; bitMask; bitMask <<= 1) {
	OneWire::write_bit( (bitMask & v)?1:0);
    }
    if ( !power) {
	noInterrupts();
	DIRECT_MODE_INPUT(baseReg, bitmask);
	DIRECT_WRITE_LOW(baseReg, bitmask);
	interrupts();
    }
}

void OneWire::write_bytes(const uint8_t *buf, uint16_t count, bool power /* = 0 */) {
  for (uint16_t i = 0 ; i < count ; i++)
    write(buf[i]);
  if (!power) {
    noInterrupts();
    DIRECT_MODE_INPUT(baseReg, bitmask);
    DIRECT_WRITE_LOW(baseReg, bitmask);
    interrupts();
  }
}
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

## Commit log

2017-12-15 Included ArduinoJson as a submodule in Required Libraries directory
2018-01-04 Code is working Preliminary fully functional UI and Arduino PID controlled heater Now need to add in functionality for the PID setpoints to be changed in real time.
    [Bioe3090_Incubator_Schematic.fzz]
2018-01-05 JSON messaging from matlab to arduino working - Works for temperature setpoint - Still Need to add PID textboxes on UI and text fields to show current temperature values in UI
2018-01-05 Code is working
    Need to add comments to make the code more understandable. Code now
    works to send and receieve json messages. If the recieved json message
    is not correctly formatted, it is ignored and subsequent correctly
    formatted json messages will still work.
    [Bioe3090_Incubator.ino]
2018-01-05 Time is now plotted on x-axes
    Time was incorporated in the JSON return message from arduino.
    Time is now plotted on x-axes.
    Still need to record the data in a file.
2018-01-06 Data is now logged in csv format Inside, Outside, Setpoint, PID, time logged Now I need to go back through the code and clean up / document
    [test.csv]
2018-01-12 Data can now be logged ToDo - Monitor and record battery voltage
    [Bioe3090_Incubator_Schematic.fzz, test.csv]
2018-01-15 README updated, code refactored Everything is working Need to add voltage monitoring.
2018-01-18 Updated Schematic to include voltage circuit
    [Bioe3090_Incubator_Schematic.fzz]
2018-01-24 Battery Voltage is working
    Battery voltage is now working and the data is being recorded in csv
    format.
    On branch battery_voltage_dev
    Changes to be committed:
    modified: Bioe3090_Incubator.ino
    modified: Diagrams/Bioe3090_Incubator_Schematic.fzz
    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
    [Bioe3090_Incubator_Schematic.fzz, test.csv]
2018-01-24 Moved files and folders
    Updated file architecture to make it easer for others to use and
    understand what is going on. Also modified fritzing.
    On branch development
    deleted: Matlab/PID_Datalogger/PlotSerial/html/README.html
    deleted: Matlab/PID_Datalogger/PlotSerial/test.csv
    deleted: Matlab/PID_Datalogger/PlotSerial/test2.csv
    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
    [Bioe3090_Incubator_Schematic.fzz, test.csv]
2018-01-31 Writing slides
    [Bioe3090_Incubator_Schematic.fzz]
2018-02-09 Minor Changes
    [Bioe3090_Incubator_Schematic.fzz]
2018-02-18 Schematic Changea Changes to be committed: new file: Diagrams/Bioe3090_Incubator_Schematic.pdf new file: Diagrams/Bioe3090_Incubator_Schematic_bb.png

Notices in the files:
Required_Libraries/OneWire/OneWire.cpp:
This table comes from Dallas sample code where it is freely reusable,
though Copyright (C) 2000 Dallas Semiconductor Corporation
